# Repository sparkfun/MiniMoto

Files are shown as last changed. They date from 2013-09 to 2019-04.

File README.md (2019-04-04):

**NOTE:** *This product has been retired from our catalog. If you are looking for more up-to-date info, please check out some of these resources to see how other users are still hacking and improving on this product.*
* *[SparkFun Forum](https://forum.sparkfun.com/)*
* *[Comments Here on GitHub](https://github.com/sparkfun/MiniMoto/issues)*
* *[IRC Channel](https://www.sparkfun.com/news/263)*

SparkFun MiniMoto Breakout - DRV8830
=========================================

SparkFun MiniMoto Breakout - DRV8830

[*SparkFun MiniMoto Breakout - DRV8830(BOB-11890)*](https://www.sparkfun.com/products/11890)

The MiniMoto is a breakout board for the DRV8830 I<sup>2</sup>C DC motor driver. It operates between 2.7V to 6.8V

Repository Contents
-------------------
* **/Hardware** - All Eagle design files (.brd, .sch)
* **/Libraries** - All Arduino libraries and board examples
* **/Production** - Test bed files and production panel files

Documentation
--------------
* **[Library](https://github.com/sparkfun/SparkFun_MiniMoto_Arduino_Library)** - Arduinolibrary for the MiniMoto.
* **[Hookup Guide](https://learn.sparkfun.com/tutorials/minimoto-drv8830-hookup-guide)** - Basic hookup guide for the MiniMoto.
* **[SparkFun Fritzing repo](https://github.com/sparkfun/Fritzing_Parts)** - Fritzing diagrams for SparkFun products.
* **[SparkFun 3D Model repo](https://github.com/sparkfun/3D_Models)** - 3D models of SparkFun products. 

License Information
-------------------
This product is _**open source**_! 

The **hardware** is released under [Creative Commons ShareAlike 4.0 International](https://creativecommons.org/licenses/by-sa/4.0/).

The **code** is beerware; if you see me (or any other SparkFun employee) at the local, and you've found our code helpful, please buy us a round!

Please use, reuse, and modify these files as you see fit. Please maintain attribution to SparkFun Electronics and release anything derivative under the same license.

Distributed as-is; no warranty is given.

- Your friends at SparkFun.

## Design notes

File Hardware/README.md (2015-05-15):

SparkFun <PRODUCT NAME> Design Files
=====================================

The .sch and .brd files hare are Eagle CAD schematic and PCB design files from SparkFun Electronics.
A freeware version of Eagle can be found [here](http://www.cadsoftusa.com/download-eagle/freeware/). 

License
---------
This product is open source! 
The hardware is released under [Creative Commons ShareAlike 4.0 International](https://creativecommons.org/licenses/by-sa/4.0/).

Please use, reuse, and modify these files as you see fit. Please maintain attribution to SparkFun Electronics and release anything derivative under the same license.

Distributed as-is; no warranty is given.

- Your friends at SparkFun.

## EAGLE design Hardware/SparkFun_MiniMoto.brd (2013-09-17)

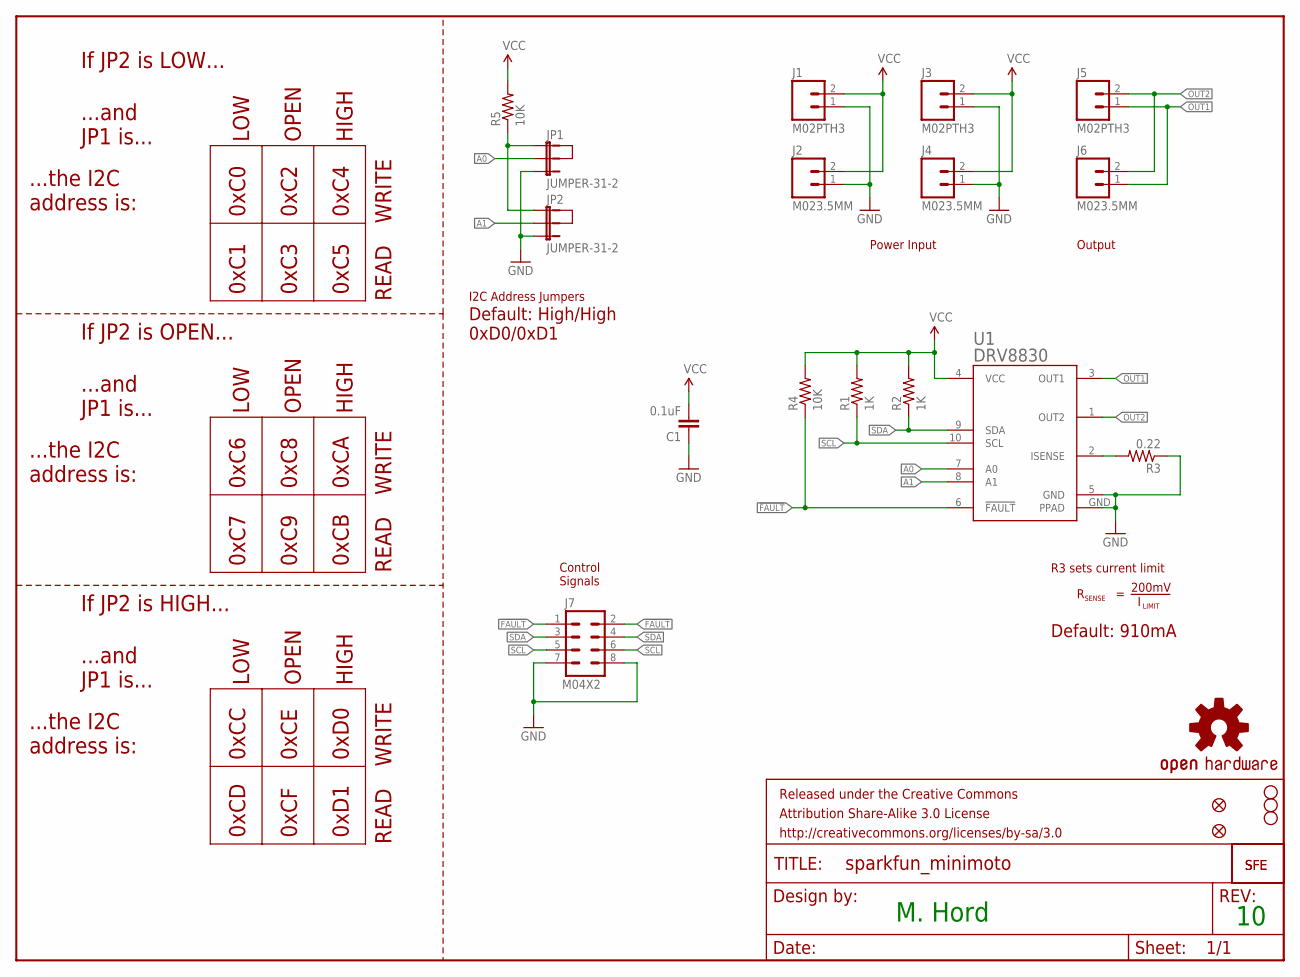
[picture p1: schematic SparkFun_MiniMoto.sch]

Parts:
C1: 0.1uF; 0603-CAP
FID1, FID2: FIDUCIALUFIDUCIAL; MICRO-FIDUCIAL
FRAME1: FRAME-LETTER; CREATIVE_COMMONS
J1, J3, J5: M02PTH3; 1X02_LONGPADS
J2, J4, J6: M023.5MM; SCREWTERMINAL-3.5MM-2
J7: M04X2; 2X4
JP1, JP2: JUMPER-31-2; SJ_3_PASTE1&2
LOGO1, LOGO3: LOGO-SFESK; SFE-LOGO-FLAME
LOGO2: OSHW-LOGOS; OSHW-LOGO-S
R1, R2: 1K; 0603-RES
R3: 0.22; 0805
R4, R5: 10K; 0603-RES
STANDOFF1, STANDOFF2, STANDOFF3: STAND-OFF
U1: DRV8830; MSOP-10-GNDPAD

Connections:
!FAULT: J7.1, J7.2, R4.1, U1.6 (!FAULT)
A0: JP1.2, U1.7 (A0)
A1: JP2.2, U1.8 (A1)
GND: C1.1, J1.1, J2.1, J3.1, J4.1, J7.7, J7.8, JP1.3, JP2.3, R3.1, U1.5 (GND), U1.GND (PPAD)
unnamed: JP1.1, JP2.1, R5.1
unnamed: R3.2, U1.2 (ISENSE)
OUT1: J5.1, J6.1, U1.3 (OUT1)
OUT2: J5.2, J6.2, U1.1 (OUT2)
SCL: J7.5, J7.6, R1.1, U1.10 (SCL)
SDA: J7.3, J7.4, R2.1, U1.9 (SDA)
VCC: C1.2, J1.2, J2.2, J3.2, J4.2, R1.2, R2.2, R4.2, R5.2, U1.4 (VCC)

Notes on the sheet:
M. Hord
If JP2 is LOW...
HIGH
LOW
OPEN
...and JP1 is...
...the I2C address is:
0xC0
0xC2
0xC4
0xC1
0xC3
0xC5
WRITE
READ
If JP2 is OPEN...
0xC6
0xC8
0xCA
0xC7
0xC9
0xCB
If JP2 is HIGH...
0xCC
0xCE
0xD0
0xCD
0xCF
0xD1
R3 sets current limit
SENSE
200mV
LIMIT
Control Signals
Power Input
Output
I2C Address Jumpers
Default: High/High 0xD0/0xD1
Default: 910mA

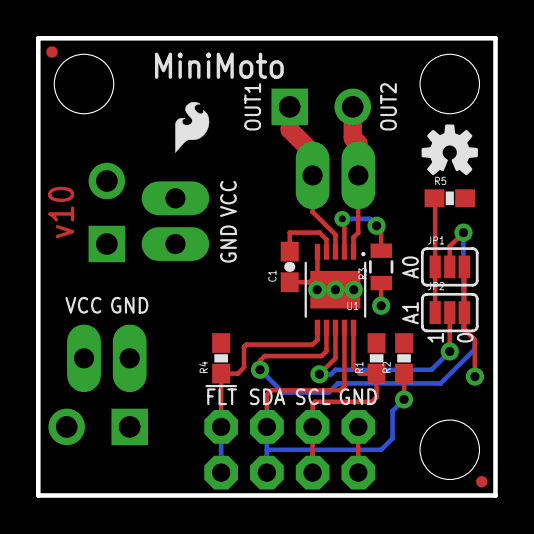
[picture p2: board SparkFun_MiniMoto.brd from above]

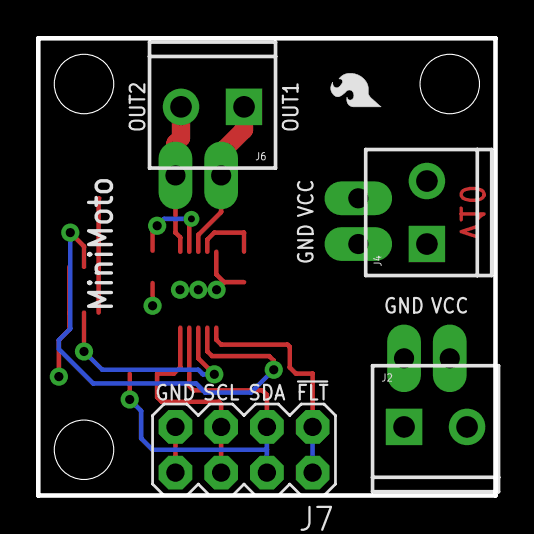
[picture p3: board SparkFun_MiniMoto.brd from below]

Board: 2 copper layers, 25.4 x 25.4 mm, 25 parts (7 on the bottom side), 11 nets.

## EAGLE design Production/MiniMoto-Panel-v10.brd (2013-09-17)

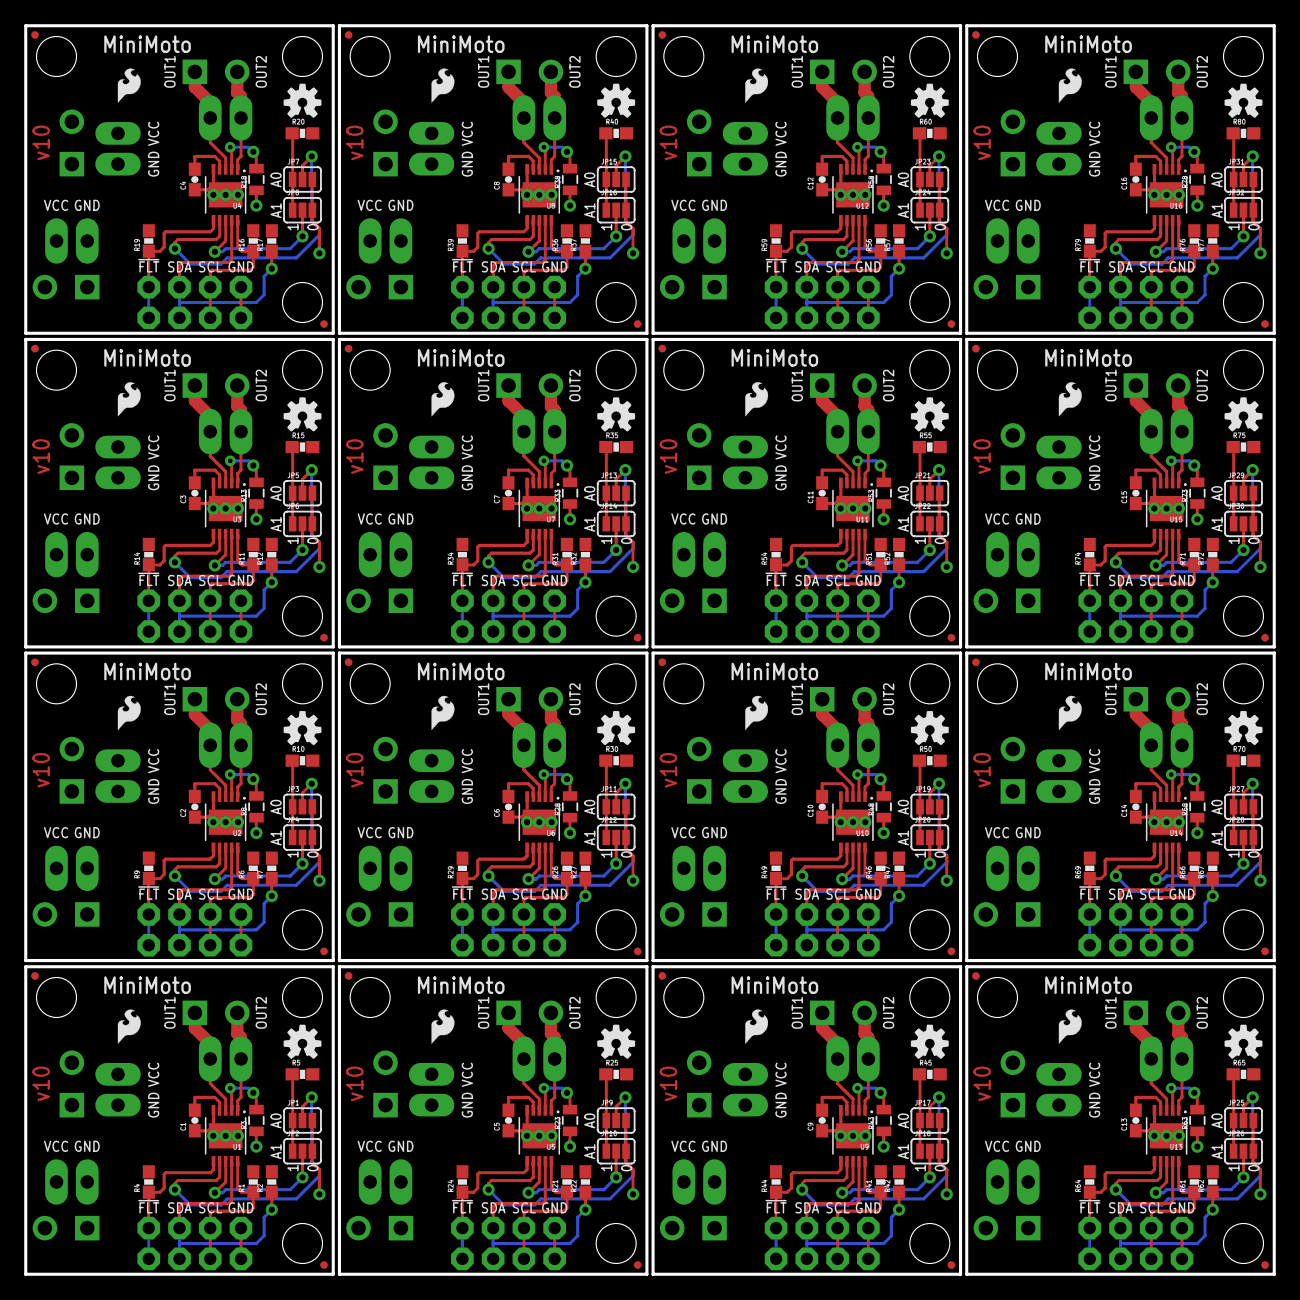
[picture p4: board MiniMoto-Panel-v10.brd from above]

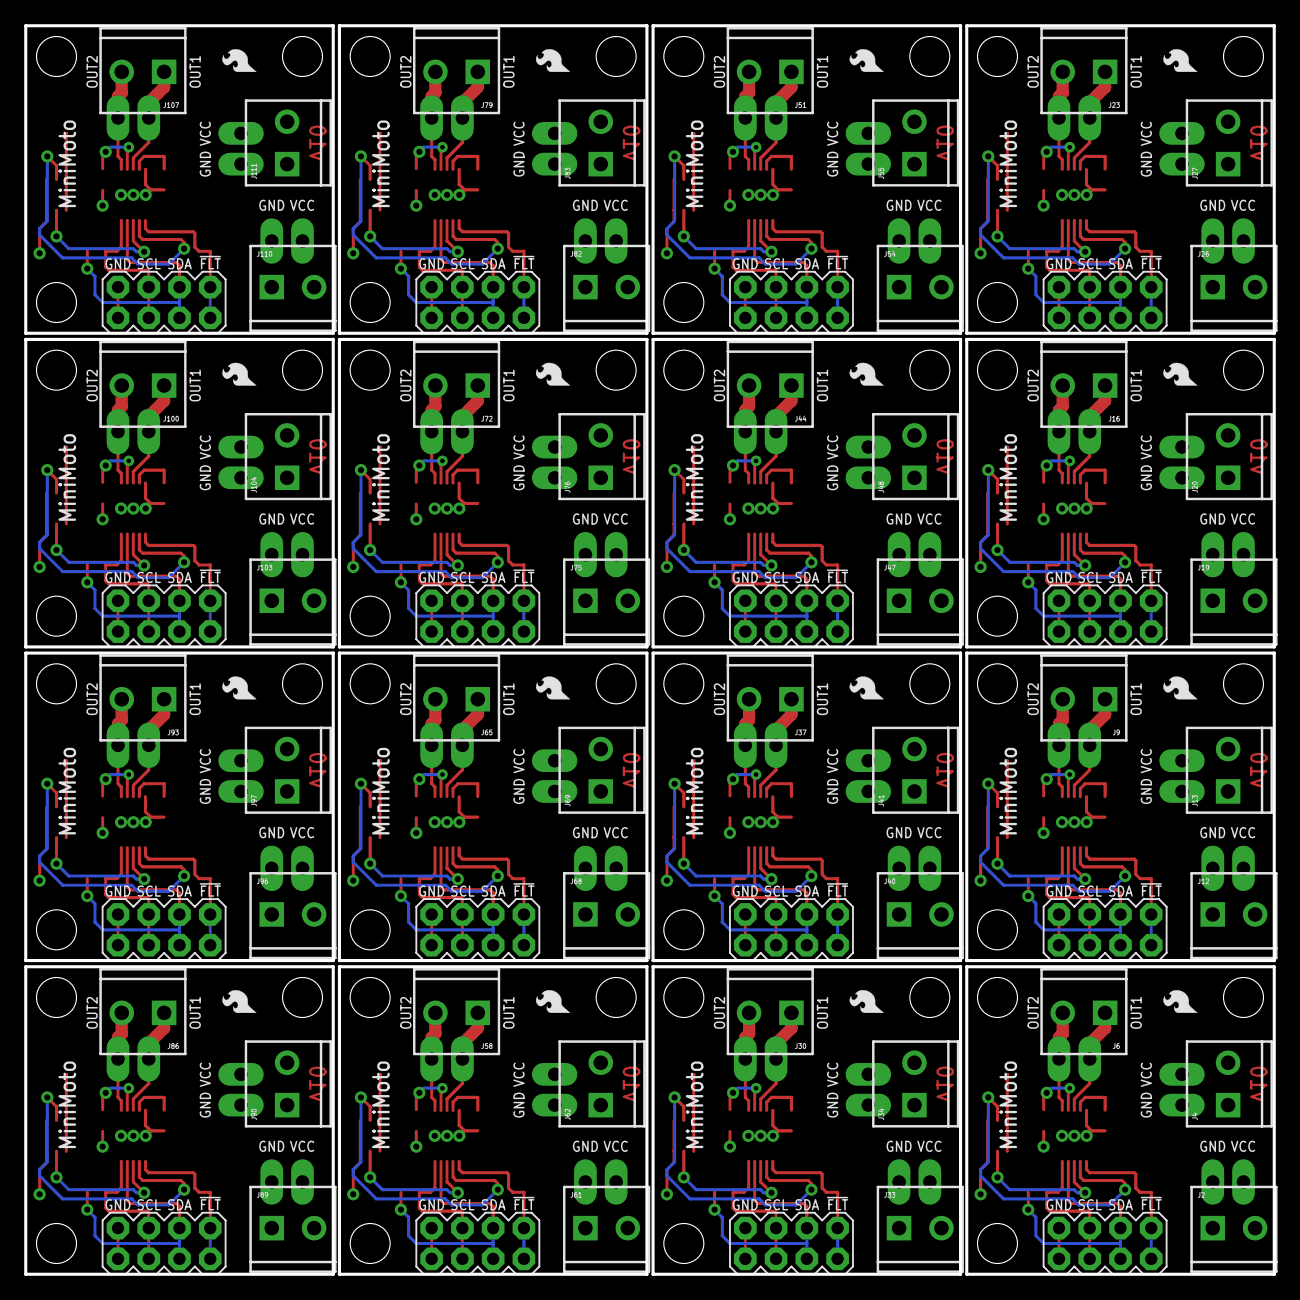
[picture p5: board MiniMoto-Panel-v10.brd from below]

Board: 2 copper layers, 103.1 x 103.1 mm, 384 parts (112 on the bottom side), 176 nets.

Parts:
C1, C2, C3, C4, C5, C6, C7, C8, C9, C10, C11, C12, C13, C14, C15, C16: 0.1uF; 0603-CAP
FID1, FID2, FID3, FID4, FID5, FID6, FID7, FID8, FID9, FID10, FID11, FID12, FID13, FID14, FID15, FID16, FID17, FID18, FID19, FID20, FID21, FID22, FID23, FID24, FID25, FID26, FID27, FID28, FID29, FID30, FID31, FID32: FIDUCIALUFIDUCIAL; MICRO-FIDUCIAL
J1, J3, J5, J8, J11, J14, J15, J18, J21, J22, J25, J28, J29, J32, J35, J36, J39, J42, J43, J46, J49, J50, J53, J56, J57, J60, J63, J64, J67, J70, J71, J74, J77, J78, J81, J84, J85, J88, J91, J92, J95, J98, J99, J102, J105, J106, J109, J112: M02PTH3; 1X02_LONGPADS
J2, J4, J6, J9, J12, J13, J16, J19, J20, J23, J26, J27, J30, J33, J34, J37, J40, J41, J44, J47, J48, J51, J54, J55, J58, J61, J62, J65, J68, J69, J72, J75, J76, J79, J82, J83, J86, J89, J90, J93, J96, J97, J100, J103, J104, J107, J110, J111: M023.5MM; SCREWTERMINAL-3.5MM-2
J7, J10, J17, J24, J31, J38, J45, J52, J59, J66, J73, J80, J87, J94, J101, J108: M04X2; 2X4
JP1, JP2, JP3, JP4, JP5, JP6, JP7, JP8, JP9, JP10, JP11, JP12, JP13, JP14, JP15, JP16, JP17, JP18, JP19, JP20, JP21, JP22, JP23, JP24, JP25, JP26, JP27, JP28, JP29, JP30, JP31, JP32: JUMPER-31-2; SJ_3_PASTE1&2
LOGO1, LOGO3, LOGO5, LOGO6, LOGO8, LOGO9, LOGO11, LOGO12, LOGO14, LOGO15, LOGO17, LOGO18, LOGO20, LOGO21, LOGO23, LOGO24, LOGO26, LOGO27, LOGO29, LOGO30, LOGO32, LOGO33, LOGO35, LOGO36, LOGO38, LOGO39, LOGO41, LOGO42, LOGO44, LOGO45, LOGO47, LOGO48: LOGO-SFESK; SFE-LOGO-FLAME
LOGO2, LOGO4, LOGO7, LOGO10, LOGO13, LOGO16, LOGO19, LOGO22, LOGO25, LOGO28, LOGO31, LOGO34, LOGO37, LOGO40, LOGO43, LOGO46: OSHW-LOGOS; OSHW-LOGO-S
R1, R2, R6, R7, R11, R12, R16, R17, R21, R22, R26, R27, R31, R32, R36, R37, R41, R42, R46, R47, R51, R52, R56, R57, R61, R62, R66, R67, R71, R72, R76, R77: 1K; 0603-RES
R3, R8, R13, R18, R23, R28, R33, R38, R43, R48, R53, R58, R63, R68, R73, R78: 0.22; 0805
R4, R5, R9, R10, R14, R15, R19, R20, R24, R25, R29, R30, R34, R35, R39, R40, R44, R45, R49, R50, R54, R55, R59, R60, R64, R65, R69, R70, R74, R75, R79, R80: 10K; 0603-RES
STANDOFF1, STANDOFF2, STANDOFF3, STANDOFF4, STANDOFF5, STANDOFF6, STANDOFF7, STANDOFF8, STANDOFF9, STANDOFF10, STANDOFF11, STANDOFF12, STANDOFF13, STANDOFF14, STANDOFF15, STANDOFF16, STANDOFF17, STANDOFF18, STANDOFF19, STANDOFF20, STANDOFF21, STANDOFF22, STANDOFF23, STANDOFF24, STANDOFF25, STANDOFF26, STANDOFF27, STANDOFF28, STANDOFF29, STANDOFF30, STANDOFF31, STANDOFF32, STANDOFF33, STANDOFF34, STANDOFF35, STANDOFF36, STANDOFF37, STANDOFF38, STANDOFF39, STANDOFF40, STANDOFF41, STANDOFF42, STANDOFF43, STANDOFF44, STANDOFF45, STANDOFF46, STANDOFF47, STANDOFF48: STAND-OFF
U1, U2, U3, U4, U5, U6, U7, U8, U9, U10, U11, U12, U13, U14, U15, U16: DRV8830; MSOP-10-GNDPAD

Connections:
!FAULT: J7.1, J7.2, R4.1, U1.6
!FAULT1: J10.1, J10.2, R9.1, U2.6
!FAULT2: J17.1, J17.2, R14.1, U3.6
!FAULT3: J24.1, J24.2, R19.1, U4.6
!FAULT4: J31.1, J31.2, R24.1, U5.6
!FAULT5: J38.1, J38.2, R29.1, U6.6
!FAULT6: J45.1, J45.2, R34.1, U7.6
!FAULT7: J52.1, J52.2, R39.1, U8.6
!FAULT8: J59.1, J59.2, R44.1, U9.6
!FAULT9: J66.1, J66.2, R49.1, U10.6
!FAULT10: J73.1, J73.2, R54.1, U11.6
!FAULT11: J80.1, J80.2, R59.1, U12.6
!FAULT12: J87.1, J87.2, R64.1, U13.6
!FAULT13: J94.1, J94.2, R69.1, U14.6
!FAULT14: J101.1, J101.2, R74.1, U15.6
!FAULT15: J108.1, J108.2, R79.1, U16.6
A0: JP1.2, U1.7
A1: JP2.2, U1.8
A2: JP3.2, U2.7
A3: JP4.2, U2.8
A4: JP5.2, U3.7
A5: JP6.2, U3.8
A6: JP7.2, U4.7
A7: JP8.2, U4.8
A8: JP9.2, U5.7
A9: JP10.2, U5.8
A10: JP11.2, U6.7
A11: JP12.2, U6.8
A12: JP13.2, U7.7
A13: JP14.2, U7.8
A14: JP15.2, U8.7
A15: JP16.2, U8.8
A16: JP17.2, U9.7
A17: JP18.2, U9.8
A18: JP19.2, U10.7
A19: JP20.2, U10.8
A20: JP21.2, U11.7
A21: JP22.2, U11.8
A22: JP23.2, U12.7
A23: JP24.2, U12.8
A24: JP25.2, U13.7
A25: JP26.2, U13.8
A26: JP27.2, U14.7
A27: JP28.2, U14.8
A28: JP29.2, U15.7
A29: JP30.2, U15.8
A30: JP31.2, U16.7
A31: JP32.2, U16.8
GND: C1.1, J1.1, J2.1, J3.1, J4.1, J7.7, J7.8, JP1.3, JP2.3, R3.1, U1.5, U1.GND
GND1: C2.1, J10.7, J10.8, J11.1, J12.1, J13.1, J14.1, JP3.3, JP4.3, R8.1, U2.5, U2.GND
GND2: C3.1, J17.7, J17.8, J18.1, J19.1, J20.1, J21.1, JP5.3, JP6.3, R13.1, U3.5, U3.GND
GND3: C4.1, J24.7, J24.8, J25.1, J26.1, J27.1, J28.1, JP7.3, JP8.3, R18.1, U4.5, U4.GND
GND4: C5.1, J31.7, J31.8, J32.1, J33.1, J34.1, J35.1, JP9.3, JP10.3, R23.1, U5.5, U5.GND
GND5: C6.1, J38.7, J38.8, J39.1, J40.1, J41.1, J42.1, JP11.3, JP12.3, R28.1, U6.5, U6.GND
GND6: C7.1, J45.7, J45.8, J46.1, J47.1, J48.1, J49.1, JP13.3, JP14.3, R33.1, U7.5, U7.GND
GND7: C8.1, J52.7, J52.8, J53.1, J54.1, J55.1, J56.1, JP15.3, JP16.3, R38.1, U8.5, U8.GND
GND8: C9.1, J59.7, J59.8, J60.1, J61.1, J62.1, J63.1, JP17.3, JP18.3, R43.1, U9.5, U9.GND
GND9: C10.1, J66.7, J66.8, J67.1, J68.1, J69.1, J70.1, JP19.3, JP20.3, R48.1, U10.5, U10.GND
GND10: C11.1, J73.7, J73.8, J74.1, J75.1, J76.1, J77.1, JP21.3, JP22.3, R53.1, U11.5, U11.GND
GND11: C12.1, J80.7, J80.8, J81.1, J82.1, J83.1, J84.1, JP23.3, JP24.3, R58.1, U12.5, U12.GND
GND12: C13.1, J87.7, J87.8, J88.1, J89.1, J90.1, J91.1, JP25.3, JP26.3, R63.1, U13.5, U13.GND
GND13: C14.1, J94.7, J94.8, J95.1, J96.1, J97.1, J98.1, JP27.3, JP28.3, R68.1, U14.5, U14.GND
GND14: C15.1, J101.7, J101.8, J102.1, J103.1, J104.1, J105.1, JP29.3, JP30.3, R73.1, U15.5, U15.GND
GND15: C16.1, J108.7, J108.8, J109.1, J110.1, J111.1, J112.1, JP31.3, JP32.3, R78.1, U16.5, U16.GND
unnamed: JP1.1, JP2.1, R5.1
unnamed: R8.2, U2.2
unnamed: R3.2, U1.2
unnamed: JP3.1, JP4.1, R10.1
unnamed: R13.2, U3.2
unnamed: JP5.1, JP6.1, R15.1
unnamed: R18.2, U4.2
unnamed: JP7.1, JP8.1, R20.1
unnamed: R23.2, U5.2
unnamed: JP9.1, JP10.1, R25.1
unnamed: R28.2, U6.2
unnamed: JP11.1, JP12.1, R30.1
unnamed: R33.2, U7.2
unnamed: JP13.1, JP14.1, R35.1
unnamed: R38.2, U8.2
unnamed: JP15.1, JP16.1, R40.1
unnamed: R43.2, U9.2
unnamed: JP17.1, JP18.1, R45.1
unnamed: R48.2, U10.2
unnamed: JP19.1, JP20.1, R50.1
unnamed: R53.2, U11.2
unnamed: JP21.1, JP22.1, R55.1
unnamed: R58.2, U12.2
unnamed: JP23.1, JP24.1, R60.1
unnamed: R63.2, U13.2
unnamed: JP25.1, JP26.1, R65.1
unnamed: R68.2, U14.2
unnamed: JP27.1, JP28.1, R70.1
unnamed: R73.2, U15.2
unnamed: JP29.1, JP30.1, R75.1
unnamed: R78.2, U16.2
unnamed: JP31.1, JP32.1, R80.1
OUT1: J5.1, J6.1, U1.3
OUT2: J5.2, J6.2, U1.1
OUT3: J8.1, J9.1, U2.3
OUT4: J8.2, J9.2, U2.1
OUT5: J15.1, J16.1, U3.3
OUT6: J15.2, J16.2, U3.1
OUT7: J22.1, J23.1, U4.3
OUT8: J22.2, J23.2, U4.1
OUT9: J29.1, J30.1, U5.3
OUT10: J29.2, J30.2, U5.1
OUT11: J36.1, J37.1, U6.3
OUT12: J36.2, J37.2, U6.1
OUT13: J43.1, J44.1, U7.3
OUT14: J43.2, J44.2, U7.1
OUT15: J50.1, J51.1, U8.3
OUT16: J50.2, J51.2, U8.1
OUT17: J57.1, J58.1, U9.3
OUT18: J57.2, J58.2, U9.1
OUT19: J64.1, J65.1, U10.3
OUT20: J64.2, J65.2, U10.1
OUT21: J71.1, J72.1, U11.3
OUT22: J71.2, J72.2, U11.1
OUT23: J78.1, J79.1, U12.3
OUT24: J78.2, J79.2, U12.1
OUT25: J85.1, J86.1, U13.3
OUT26: J85.2, J86.2, U13.1
OUT27: J92.1, J93.1, U14.3
OUT28: J92.2, J93.2, U14.1
OUT29: J99.1, J100.1, U15.3
OUT30: J99.2, J100.2, U15.1
OUT31: J106.1, J107.1, U16.3
OUT32: J106.2, J107.2, U16.1
SCL: J7.5, J7.6, R1.1, U1.10
SCL1: J10.5, J10.6, R6.1, U2.10
SCL2: J17.5, J17.6, R11.1, U3.10
SCL3: J24.5, J24.6, R16.1, U4.10
SCL4: J31.5, J31.6, R21.1, U5.10
SCL5: J38.5, J38.6, R26.1, U6.10
SCL6: J45.5, J45.6, R31.1, U7.10
SCL7: J52.5, J52.6, R36.1, U8.10
SCL8: J59.5, J59.6, R41.1, U9.10
SCL9: J66.5, J66.6, R46.1, U10.10
SCL10: J73.5, J73.6, R51.1, U11.10
SCL11: J80.5, J80.6, R56.1, U12.10
SCL12: J87.5, J87.6, R61.1, U13.10
SCL13: J94.5, J94.6, R66.1, U14.10
SCL14: J101.5, J101.6, R71.1, U15.10
SCL15: J108.5, J108.6, R76.1, U16.10
SDA: J7.3, J7.4, R2.1, U1.9
SDA1: J10.3, J10.4, R7.1, U2.9
SDA2: J17.3, J17.4, R12.1, U3.9
SDA3: J24.3, J24.4, R17.1, U4.9
SDA4: J31.3, J31.4, R22.1, U5.9
SDA5: J38.3, J38.4, R27.1, U6.9
SDA6: J45.3, J45.4, R32.1, U7.9
SDA7: J52.3, J52.4, R37.1, U8.9
SDA8: J59.3, J59.4, R42.1, U9.9
SDA9: J66.3, J66.4, R47.1, U10.9
SDA10: J73.3, J73.4, R52.1, U11.9
SDA11: J80.3, J80.4, R57.1, U12.9
SDA12: J87.3, J87.4, R62.1, U13.9
SDA13: J94.3, J94.4, R67.1, U14.9
SDA14: J101.3, J101.4, R72.1, U15.9
SDA15: J108.3, J108.4, R77.1, U16.9
VCC: C1.2, J1.2, J2.2, J3.2, J4.2, R1.2, R2.2, R4.2, R5.2, U1.4
VCC1: C2.2, J11.2, J12.2, J13.2, J14.2, R6.2, R7.2, R9.2, R10.2, U2.4
VCC2: C3.2, J18.2, J19.2, J20.2, J21.2, R11.2, R12.2, R14.2, R15.2, U3.4
VCC3: C4.2, J25.2, J26.2, J27.2, J28.2, R16.2, R17.2, R19.2, R20.2, U4.4
VCC4: C5.2, J32.2, J33.2, J34.2, J35.2, R21.2, R22.2, R24.2, R25.2, U5.4
VCC5: C6.2, J39.2, J40.2, J41.2, J42.2, R26.2, R27.2, R29.2, R30.2, U6.4
VCC6: C7.2, J46.2, J47.2, J48.2, J49.2, R31.2, R32.2, R34.2, R35.2, U7.4
VCC7: C8.2, J53.2, J54.2, J55.2, J56.2, R36.2, R37.2, R39.2, R40.2, U8.4
VCC8: C9.2, J60.2, J61.2, J62.2, J63.2, R41.2, R42.2, R44.2, R45.2, U9.4
VCC9: C10.2, J67.2, J68.2, J69.2, J70.2, R46.2, R47.2, R49.2, R50.2, U10.4
VCC10: C11.2, J74.2, J75.2, J76.2, J77.2, R51.2, R52.2, R54.2, R55.2, U11.4
VCC11: C12.2, J81.2, J82.2, J83.2, J84.2, R56.2, R57.2, R59.2, R60.2, U12.4
VCC12: C13.2, J88.2, J89.2, J90.2, J91.2, R61.2, R62.2, R64.2, R65.2, U13.4
VCC13: C14.2, J95.2, J96.2, J97.2, J98.2, R66.2, R67.2, R69.2, R70.2, U14.4
VCC14: C15.2, J102.2, J103.2, J104.2, J105.2, R71.2, R72.2, R74.2, R75.2, U15.4
VCC15: C16.2, J109.2, J110.2, J111.2, J112.2, R76.2, R77.2, R79.2, R80.2, U16.4

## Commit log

2013-06-03 Initial commit for protos
    [MiniMoto.brd, MiniMoto.sch]
2013-07-16 Tweaks for release, add lib
    [MiniMoto.brd, MiniMoto.sch]
2013-07-24 Updated to v10 for release
    [MiniMoto.brd, MiniMoto.sch]
2013-07-25 Production Readied
    [MiniMoto-Panel-v10.brd, MiniMoto.brd, MiniMoto.sch]
2013-09-10 Reorganized Arduino folder. Moved example into library folder.
2013-09-10 Moved example into Arduino library folder.
2013-09-17 Adding Arduino Library and example code.
2014-05-23 Move library to Arduino folder, line endings
    [MiniMoto-Panel-v10.brd, MiniMoto.brd, MiniMoto.sch]
2014-05-23 Revert "Move library to Arduino folder, line endings"
    This reverts commit 295bfce20a394f6c63947fa651fac41841a54c73.
    [MiniMoto-Panel-v10.brd, MiniMoto.brd, MiniMoto.sch]
2014-05-23 Move "Libraries" into "Arduino".
    I hosed this before, or rather, bash did. I'm trying to figure out how.
2015-05-15 Updating directory structure, updating readmes
    [MiniMoto-Panel-v10.brd, SparkFun_MiniMoto.brd, SparkFun_MiniMoto.sch]
2015-05-15 Squashed 'Libraries/Arduino/' content from commit 1b42fbb
    git-subtree-dir: Libraries/Arduino
    git-subtree-split: 1b42fbbbe25c134150f8e9cb268108fa5aeeab93

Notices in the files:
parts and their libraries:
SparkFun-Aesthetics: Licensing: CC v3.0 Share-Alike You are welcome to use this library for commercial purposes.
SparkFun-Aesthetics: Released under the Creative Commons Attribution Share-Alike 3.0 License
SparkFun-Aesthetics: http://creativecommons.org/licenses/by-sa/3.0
